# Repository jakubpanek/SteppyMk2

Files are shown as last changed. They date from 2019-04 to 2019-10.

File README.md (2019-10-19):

# Steppy Mk2

The goal of this project is to create a versatile robotic platform for robotic competitions.

It started with a very primitive PCB design that featured just a few, mostly through-hole components and evolved into a much more complicated design with over a hundred SMD components.

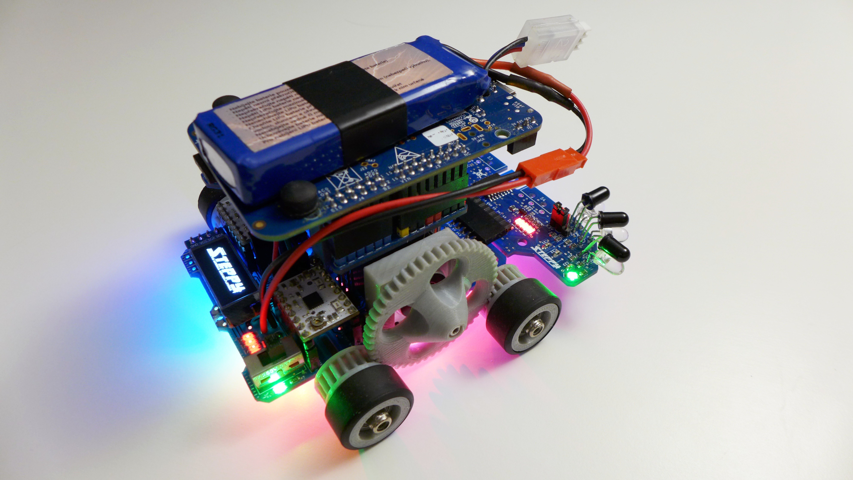
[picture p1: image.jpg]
Drag Racing


## Main features:
- NXP's FRDM dev boards, Arduino compatibility
- Two NEMA8 stepper motors
- Fits onto 100x100mm PCB for cheap manufacturing
- RGB LEDs
- OLED display
- Joystick
- Buzzer
- I²C battery voltage sensor
- Interchangeable sensor board

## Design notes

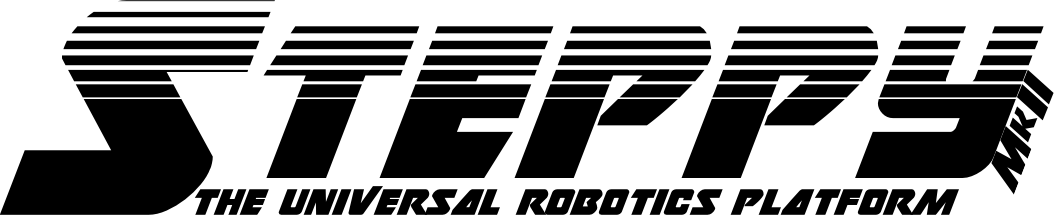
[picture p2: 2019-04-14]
Graphics/SteppyMk2.png

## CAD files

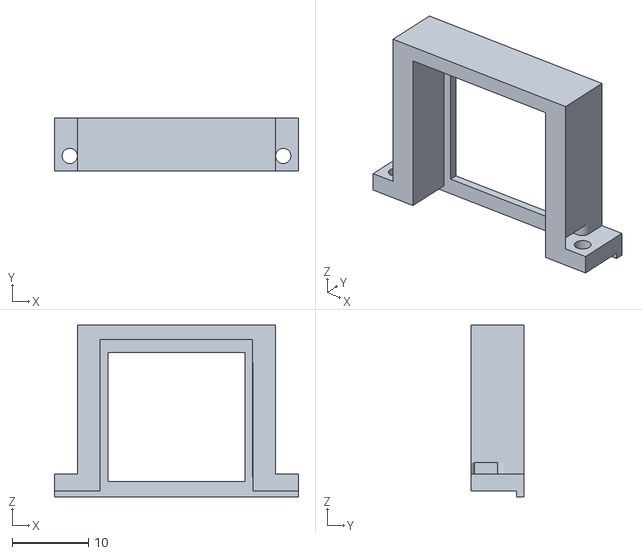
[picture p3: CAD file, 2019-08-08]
3D models/V2.0/MotorHolderSide.stl
32.0 x 7.00 x 22.5

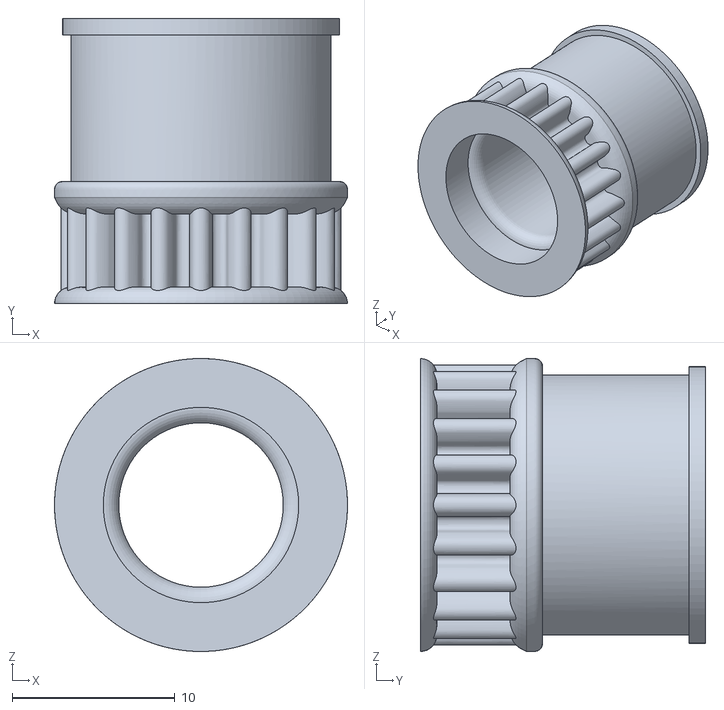
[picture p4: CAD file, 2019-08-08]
3D models/V2.0/Wheel.stl
18.0 x 17.5 x 18.0

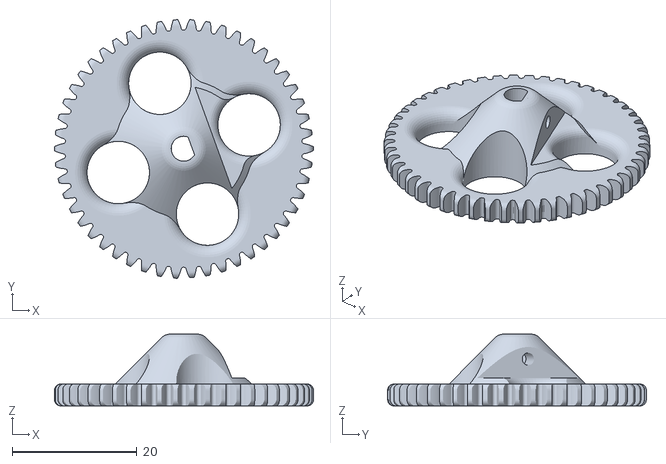
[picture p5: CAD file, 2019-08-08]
3D models/V2.0/Gear.stl
41.5 x 41.5 x 11.5

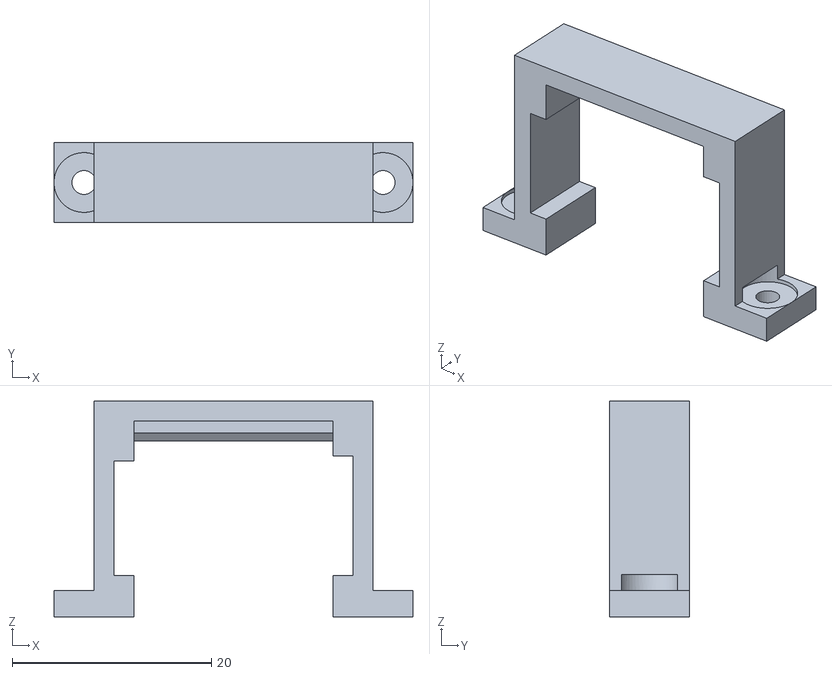
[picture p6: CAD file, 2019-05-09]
3D models/V2.0/MotorHolderMiddle.stl
36.0 x 8.00 x 21.6

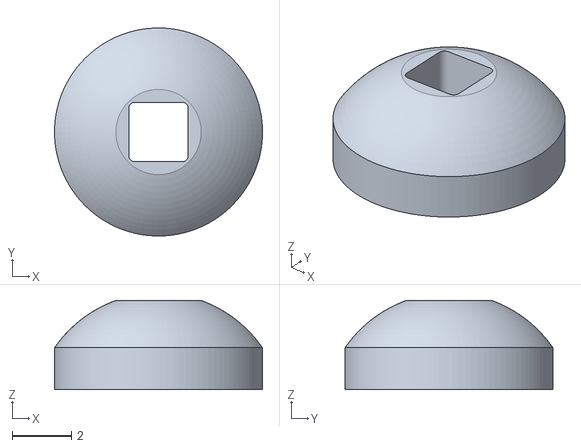
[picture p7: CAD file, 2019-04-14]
3D models/V2.0/JoystickCap.stl
7.00 x 7.00 x 3.00

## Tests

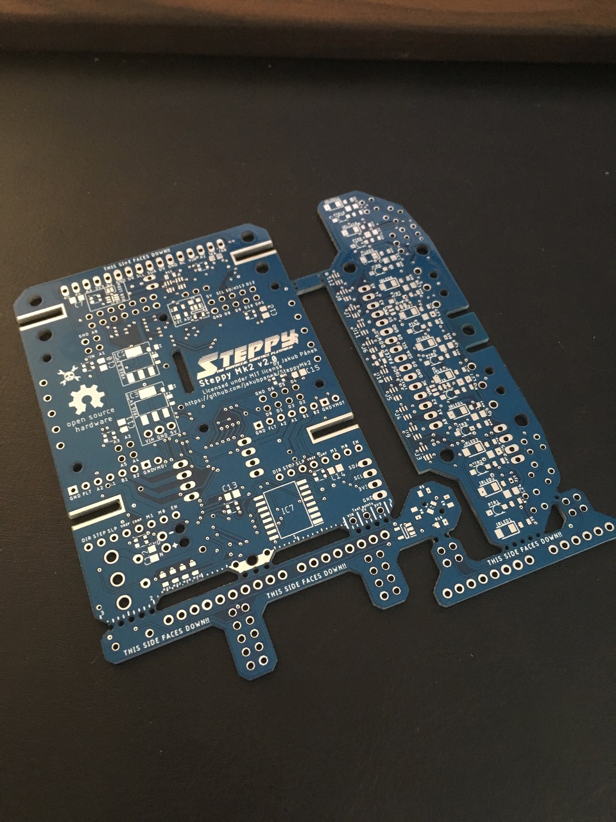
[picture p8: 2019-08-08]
Gerbers/V2.0/Result via JLCPCB/SteppyMk2V2 - 2.jpeg

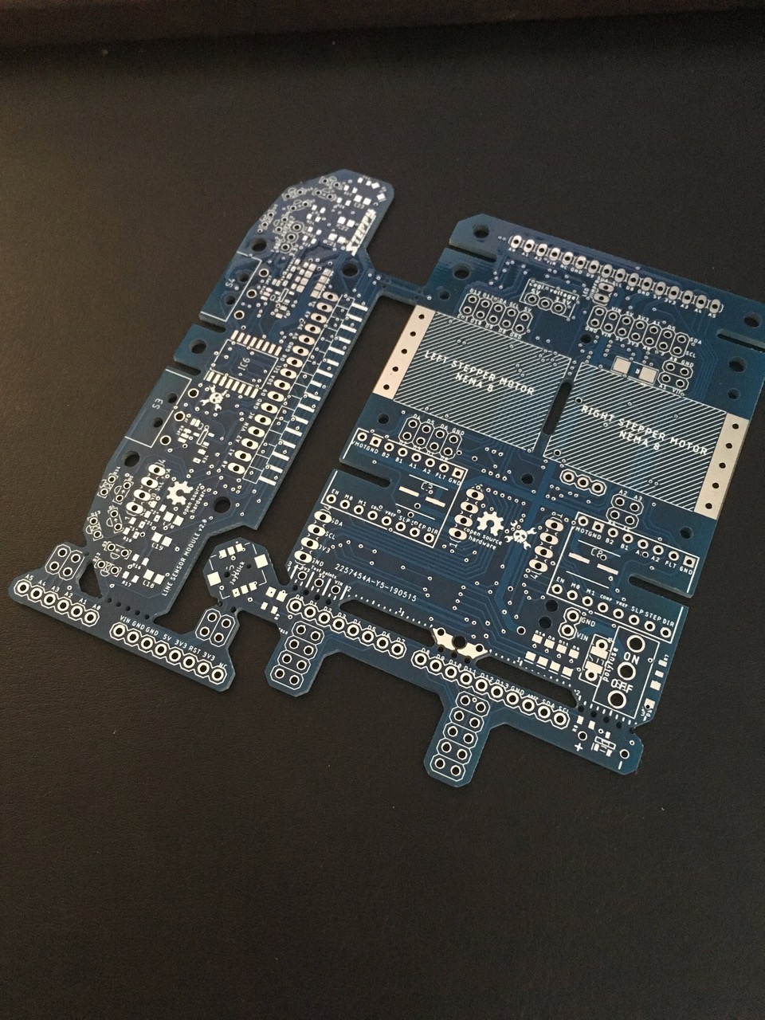
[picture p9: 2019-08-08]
Gerbers/V2.0/Result via JLCPCB/SteppyMk2V2 - 1.jpeg

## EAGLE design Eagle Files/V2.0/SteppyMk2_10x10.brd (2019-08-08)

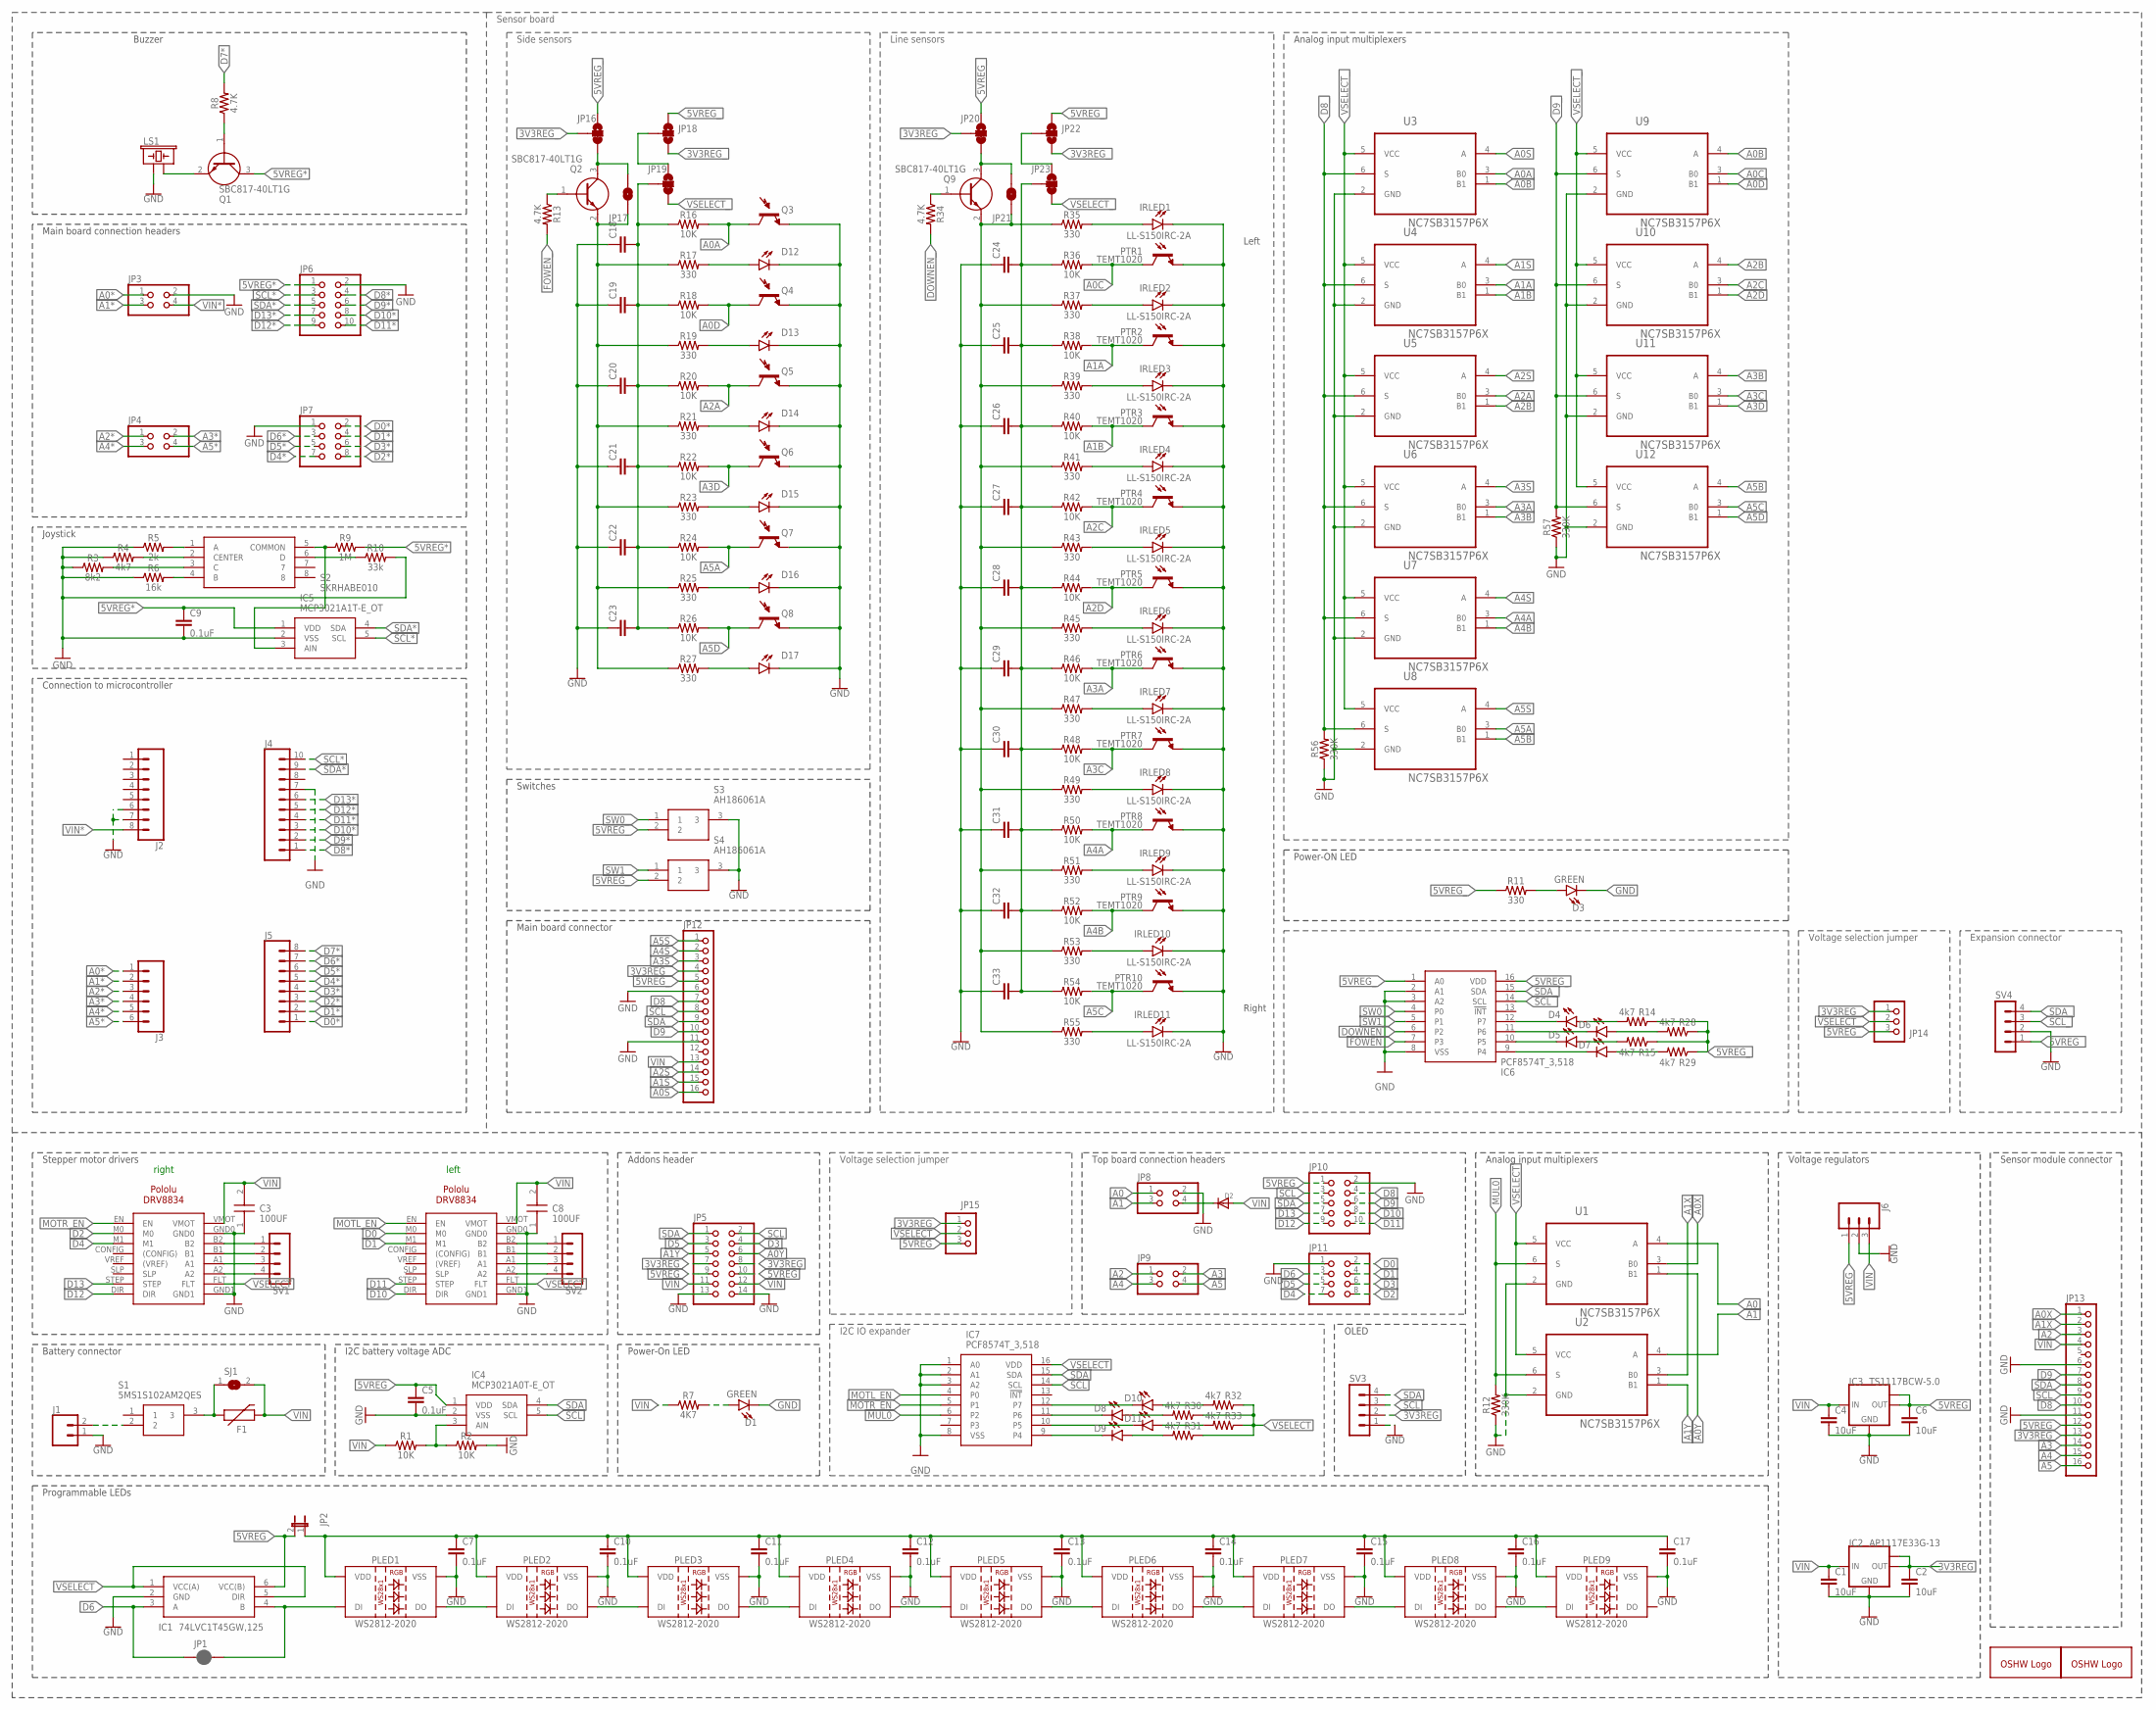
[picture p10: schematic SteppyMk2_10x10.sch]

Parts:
C1, C2, C4, C6: 10uF; 0805
C3, C8: 100UF; CAPM7058X610N
C5: 0.1uF; 0603
C7, C9, C10, C11, C12, C13, C14, C15, C16, C17: 0.1uF; C0805
C18, C19, C20, C21, C22, C23, C24, C25, C26, C27, C28, C29, C30, C31, C32, C33: C-EUC0805; C0805
D1, D3, D4, D5, D6, D7, D8, D9, D10, D11: GREEN; LED-1206
D2: DIODESMA; SMADIODE
D12, D13, D14, D15, D16, D17: LED-IRSIDE_EMITTER; LTE-302
DRV1, DRV2: POLOLU-DRV8825
F1: PPTC_PTH; PTH
GOLD_ORB_SM1: OSHWLOGOLOGO8MM; OSHW_8MM
GOLD_ORB_SM2: OSHWLOGOLOGO5MM; OSHW_5MM
IC1: 74LVC1T45GW,125; SOT65P210X110-6N
IC2: AP1117E33G-13; SOT223
IC3: TS1117BCW-5.0; SOT223
IC4: MCP3021A0T-E_OT; SOT95P280X145-5N
IC5: MCP3021A1T-E_OT; SOT95P280X145-5N
IC6, IC7: PCF8574T_3,518; SOIC127P1032X265-16N
IRLED1, IRLED2, IRLED3, IRLED4, IRLED5, IRLED6, IRLED7, IRLED8, IRLED9, IRLED10, IRLED11: LL-S150IRC-2A; LEDC3215X130N
J1: CONN_02; 1X02
J2, J5: CONN_08"; 1X08
J3: CONN_06SILK_FEMALE_PTH; 1X06
J4: CONN_10"; 1X10
J6: 455-1750-1-ND; 1X03
JP1: JUMPER-SMT_2_NC_PASTE_SILK; SMT-JUMPER_2_NC_PASTE_SILK
JP2: JP1E; JP1
JP3, JP4, JP8, JP9: PINHD-2X2; 2X02
JP5: PINHD-2X7; 2X07
JP6, JP10: PINHD-2X5; 2X05
JP7, JP11: PINHD-2X4; 2X04
JP12: PINHD-1X16/90; 1X16/90
JP13: PINHD-1X16; 1X16
JP14, JP15: PINHD-1X3; 1X03
JP16, JP19, JP20, JP23: JUMPER-SMT_3_1-NC_TRACE_NO-SILK; SMT-JUMPER_3_1-NC_TRACE_NO-SILK
JP17, JP21: JUMPER-SMT_2_NO_NO-SILK; SMT-JUMPER_2_NO_NO-SILK
JP18, JP22: JUMPER-SMT_3_NO_NO_SILK; SMT-JUMPER_3_0-NO_TRACE_NO-SILK
LS1: BUZZER-PTH_NO_SILK; BUZZER-12MM-NS
PLED1, PLED2, PLED3, PLED4, PLED5, PLED6, PLED7, PLED8, PLED9: WS2812-2020
PTR1, PTR2, PTR3, PTR4, PTR5, PTR6, PTR7, PTR8, PTR9, PTR10: TEMT1020
Q1, Q2, Q9: SBC817-40LT1G; SOT96P237X111-3N
Q3, Q4, Q5, Q6, Q7, Q8: LTR-301
R1, R2, R16, R18, R20, R22, R24, R26, R36, R38, R40, R42, R44, R46, R48, R50, R52, R54: 10K; 0805
R3: 8k2; 0805
R4, R14, R15, R28, R29, R30, R31, R32, R33: 4k7; 0805
R5: 2k; 0805
R6: 16k; 0805
R7: 4K7; 0805
R8, R13, R34: 4.7K; 0805
R9: 1M; 0805
R10: 33k; 0805
R11, R17, R19, R21, R23, R25, R27, R35, R37, R39, R41, R43, R45, R47, R49, R51, R53, R55: 330; 0805
R12, R56, R57: 330K; 0805
S1: 5MS1S102AM2QES
S2: SKRHABE010
S3, S4: AH186061A
SJ1: SJW
SV1, SV2, SV3, SV4: MA04-1
U1, U2, U3, U4, U5, U6, U7, U8, U9, U10, U11, U12: NC7SB3157P6X; SOT65P210X110-6N

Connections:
3V3REG: C2.1, IC2.2 (OUT), IC2.TAB (OUT1), JP5.7, JP5.8, JP13.13, JP15.1, SV3.2
3V3REG_: JP12.4, JP14.1, JP16.2, JP18.3, JP20.2, JP22.3
5VREG: C5.1, C6.1, IC1.6 (VCC(B)), IC3.2 (OUT), IC3.TAB (OUT1), IC4.1 (VDD), J6.1, JP2.2, JP5.9, JP5.10, JP10.1, JP13.12, JP15.3
5VREG*: C9.1, IC5.1 (VDD), JP6.1, Q1.3 (C), R9.2
5VREG_: IC6.1 (A0), IC6.16 (VDD), JP12.5, JP14.3, JP16.1, JP18.1, JP20.1, JP22.1, R11.1, R14.1, R15.1, R28.1, R29.1, S3.2, S4.2, SV4.1
A0: JP8.1, U1.4 (A)
A0*: J3.1, JP3.1
A0A: Q3.C (C1), R16.2, U3.3 (B0)
A0B: U3.1 (B1), U9.4 (A)
A0C: PTR1.1 (C), R36.2, U9.3 (B0)
A0D: Q4.C (C1), R18.2, U9.1 (B1)
A0S: JP12.16, U3.4 (A)
A0X: JP13.1, U1.3 (B0)
A0Y: JP5.6, U1.1 (B1)
A1: JP8.3, U2.4 (A)
A1*: J3.2, JP3.3
A1A: PTR2.1 (C), R38.2, U4.3 (B0)
A1B: PTR3.1 (C), R40.2, U4.1 (B1)
A1S: JP12.15, U4.4 (A)
A1X: JP13.2, U2.3 (B0)
A1Y: JP5.5, U2.1 (B1)
A2: JP9.1, JP13.3
A2*: J3.3, JP4.1
A2A: Q5.C (C1), R20.2, U5.3 (B0)
A2B: U5.1 (B1), U10.4 (A)
A2C: PTR4.1 (C), R42.2, U10.3 (B0)
A2D: PTR5.1 (C), R44.2, U10.1 (B1)
A2S: JP12.14, U5.4 (A)
A3: JP9.2, JP13.14
A3*: J3.4, JP4.2
A3A: PTR6.1 (C), R46.2, U6.3 (B0)
A3B: U6.1 (B1), U11.4 (A)
A3C: PTR7.1 (C), R48.2, U11.3 (B0)
A3D: Q6.C (C1), R22.2, U11.1 (B1)
A3S: JP12.3, U6.4 (A)
A4: JP9.3, JP13.15
A4*: J3.5, JP4.3
A4A: PTR8.1 (C), R50.2, U7.3 (B0)
A4B: PTR9.1 (C), R52.2, U7.1 (B1)
A4S: JP12.2, U7.4 (A)
A5: JP9.4, JP13.16
A5*: J3.6, JP4.4
A5A: Q7.C (C1), R24.2, U8.3 (B0)
A5B: U8.1 (B1), U12.4 (A)
A5C: PTR10.1 (C), R54.2, U12.3 (B0)
A5D: Q8.C (C1), R26.2, U12.1 (B1)
A5S: JP12.1, U8.4 (A)
D0: DRV2.M0, JP11.2
D0*: J5.1, JP7.2
D1: DRV2.M1, JP11.4
D1*: J5.2, JP7.4
D2: DRV1.M0, JP11.8
D2*: J5.3, JP7.8
D3: JP5.4, JP11.6
D3*: J5.4, JP7.6
D4: DRV1.M1, JP11.7
D4*: J5.5, JP7.7
D5: JP5.3, JP11.5
D5*: J5.6, JP7.5
D6: IC1.3 (A), JP1.1, JP11.3
D6*: J5.7, JP7.3
D7*: J5.8, R8.2
D8: JP10.4, JP13.10
D8*: J4.1, JP6.4
D8_: JP12.7, R56.2, U3.6 (S), U4.6 (S), U5.6 (S), U6.6 (S), U7.6 (S), U8.6 (S)
D9: JP10.6, JP13.7
D9*: J4.2, JP6.6
D9_: JP12.10, R57.2, U9.6 (S), U10.6 (S), U11.6 (S), U12.6 (S)
D10: DRV2.DIR, JP10.8
D10*: J4.3, JP6.8
D11: DRV2.STEP, JP10.10
D11*: J4.4, JP6.10
D12: DRV1.DIR, JP10.9
D12*: J4.5, JP6.9
D13: DRV1.STEP, JP10.7
D13*: J4.6, JP6.7
DOWNEN_: IC6.6 (P2), R34.2
FOWEN_: IC6.7 (P3), R13.2
GND: C1.2, C2.2, C3.1, C4.2, C5.2, C6.2, C7.2, C8.1, C9.2, C10.2, C11.2, C12.2, C13.2, C14.2, C15.2, C16.2, C17.2, C18.1, C19.1, C20.1, C21.1, C22.1, C23.1, C24.1, C25.1, C26.1, C27.1, C28.1, C29.1, C30.1, C31.1, C32.1, C33.1, D1.C, D3.C, D12.C, D13.C, D14.C, D15.C, D16.C, D17.C, DRV1.GND0, DRV1.GND1, DRV2.GND0, DRV2.GND1, IC1.2 (GND), IC2.1 (GND), IC3.1 (GND), IC4.2 (VSS), IC5.2 (VSS), IC6.2 (A1), IC6.3 (A2), IC6.8 (VSS), IC7.1 (A0), IC7.2 (A1), IC7.3 (A2), IC7.8 (VSS), IRLED1.2 (C), IRLED2.2 (C), IRLED3.2 (C), IRLED4.2 (C), IRLED5.2 (C), IRLED6.2 (C), IRLED7.2 (C), IRLED8.2 (C), IRLED9.2 (C), IRLED10.2 (C), IRLED11.2 (C), J1.1, J2.6, J2.7, J4.7, J6.2, JP3.2, JP5.13, JP5.14, JP6.2, JP7.1, JP8.2, JP10.2, JP11.1, JP12.6, JP12.11, JP13.6, JP13.11, LS1.+ (1), PLED1.2 (VSS), PLED2.2 (VSS), PLED3.2 (VSS), PLED4.2 (VSS), PLED5.2 (VSS), PLED6.2 (VSS), PLED7.2 (VSS), PLED8.2 (VSS), PLED9.2 (VSS), PTR1.2 (E), PTR2.2 (E), PTR3.2 (E), PTR4.2 (E), PTR5.2 (E), PTR6.2 (E), PTR7.2 (E), PTR8.2 (E), PTR9.2 (E), PTR10.2 (E), Q3.E (E1), Q4.E (E1), Q5.E (E1), Q6.E (E1), Q7.E (E1), Q8.E (E1), R2.2, R3.1, R4.1, R5.1, R6.1, R10.2, R12.1, R56.1, R57.1, S3.3, S4.3, SV3.1, SV4.2, U1.2 (GND), U2.2 (GND), U3.2 (GND), U4.2 (GND), U5.2 (GND), U6.2 (GND), U7.2 (GND), U8.2 (GND), U9.2 (GND), U10.2 (GND), U11.2 (GND), U12.2 (GND)
GND1: D6.C, IC6.11 (P6)
GND2: D5.C, IC6.10 (P5)
GND3: D7.C, IC6.9 (P4)
MOTL_EN: DRV2.EN, IC7.4 (P0)
MOTR_EN: DRV1.EN, IC7.5 (P1)
MUL0: IC7.6 (P2), R12.2, U1.6 (S), U2.6 (S)
unnamed: IRLED9.1 (A), R51.2
unnamed: IRLED2.1 (A), R37.2
unnamed: D4.A, R14.2
unnamed: D2.C, JP8.4
unnamed: Q2.1 (B), R13.1
unnamed: IRLED1.1 (A), R35.2
unnamed: IC1.4 (B), JP1.2, PLED1.3 (DI)
unnamed: D8.A, R30.2
unnamed: D11.C, IC7.10 (P5)
unnamed: D9.A, R31.2
unnamed: PLED6.1 (DO), PLED7.3 (DI)
unnamed: IRLED3.1 (A), R39.2
unnamed: PLED7.1 (DO), PLED8.3 (DI)
unnamed: PLED8.1 (DO), PLED9.3 (DI)
unnamed: D1.A, R7.2
unnamed: DRV2.B2, SV2.1
unnamed: DRV2.B1, SV2.2
unnamed: DRV2.A1, SV2.3
unnamed: DRV2.A2, SV2.4
unnamed: D6.A, R28.2
unnamed: R6.2, S2.4 (B)
unnamed: D3.A, R11.2
unnamed: IRLED4.1 (A), R41.2
unnamed: D5.A, R15.2
unnamed: R3.2, S2.3 (C)
unnamed: DRV1.B2, SV1.1
unnamed: DRV1.B1, SV1.2
unnamed: DRV1.A1, SV1.3
unnamed: DRV1.A2, SV1.4
unnamed: J1.2, S1.2
unnamed: R4.2, S2.2 (CENTER)
unnamed: LS1.- (2), Q1.2 (E)
unnamed: Q1.1 (B), R8.1
unnamed: IC4.3 (AIN), R1.2, R2.1
unnamed: R5.2, S2.1 (A)
unnamed: D10.C, IC7.12 (P7)
unnamed: IC5.3 (AIN), R9.1, S2.5 (COMMON)
unnamed: R10.1, S2.6 (D)
unnamed: D8.C, IC7.11 (P6)
unnamed: D7.A, R29.2
unnamed: D9.C, IC7.9 (P4)
unnamed: D11.A, R33.2
unnamed: D10.A, R32.2
unnamed: C7.1, C10.1, C11.1, C12.1, C13.1, C14.1, C15.1, C16.1, C17.1, JP2.1, PLED1.4 (VDD), PLED2.4 (VDD), PLED3.4 (VDD), PLED4.4 (VDD), PLED5.4 (VDD), PLED6.4 (VDD), PLED7.4 (VDD), PLED8.4 (VDD), PLED9.4 (VDD)
unnamed: IRLED5.1 (A), R43.2
unnamed: PLED2.1 (DO), PLED3.3 (DI)
unnamed: PLED3.1 (DO), PLED4.3 (DI)
unnamed: IRLED6.1 (A), R45.2
unnamed: PLED4.1 (DO), PLED5.3 (DI)
unnamed: IRLED7.1 (A), R47.2
unnamed: PLED5.1 (DO), PLED6.3 (DI)
unnamed: JP16.3, JP17.2, Q2.3 (C)
unnamed: IRLED8.1 (A), R49.2
unnamed: JP18.2, JP19.1
unnamed: PLED1.1 (DO), PLED2.3 (DI)
unnamed: JP22.2, JP23.1
unnamed: JP20.3, JP21.2, Q9.3 (C)
unnamed: D4.C, IC6.12 (P7)
unnamed: IRLED10.1 (A), R53.2
unnamed: IRLED11.1 (A), R55.2
unnamed: D12.A, R17.2
unnamed: D13.A, R19.2
unnamed: Q9.1 (B), R34.1
unnamed: D14.A, R21.2
unnamed: F1.P$1 (1), S1.3, SJ1.1
unnamed: D15.A, R23.2
unnamed: JP21.1, Q9.2 (E), R35.1, R37.1, R39.1, R41.1, R43.1, R45.1, R47.1, R49.1, R51.1, R53.1, R55.1
unnamed: D16.A, R25.2
unnamed: D17.A, R27.2
unnamed: JP17.1, Q2.2 (E), R17.1, R19.1, R21.1, R23.1, R25.1, R27.1
NE9878: C24.2, C25.2, C26.2, C27.2, C28.2, C29.2, C30.2, C31.2, C32.2, C33.2, JP23.2, R36.1, R38.1, R40.1, R42.1, R44.1, R46.1, R48.1, R50.1, R52.1, R54.1
NET56SDFSF: C18.2, C19.2, C20.2, C21.2, C22.2, C23.2, JP19.2, R16.1, R18.1, R20.1, R22.1, R24.1, R26.1
SCL: IC4.5 (SCL), IC7.14 (SCL), JP5.2, JP10.3, JP13.9, SV3.3
SCL*: IC5.5 (SCL), J4.10, JP6.3
SCL_: IC6.14 (SCL), JP12.8, SV4.3
SDA: IC4.4 (SDA), IC7.15 (SDA), JP5.1, JP10.5, JP13.8, SV3.4
SDA*: IC5.4 (SDA), J4.9, JP6.5
SDA_: IC6.15 (SDA), JP12.9, SV4.4
SW0_: IC6.4 (P0), S3.1
SW1_: IC6.5 (P1), S4.1
VIN: C1.1, C3.2, C4.1, C8.2, D2.A, DRV1.VMOT, DRV2.VMOT, F1.P$2 (2), IC2.3 (IN), IC3.3 (IN), J6.3, JP5.11, JP5.12, JP13.4, R1.1, R7.1, SJ1.2
VIN*: J2.8, JP3.4
VIN_: JP12.13
VSELECT: DRV1.FLT, DRV2.FLT, IC1.1 (VCC(A)), IC1.5 (DIR), IC7.16 (VDD), JP15.2, R30.1, R31.1, R32.1, R33.1, U1.5 (VCC), U2.5 (VCC)
VSELECT_: JP14.2, JP19.3, JP23.3, U3.5 (VCC), U4.5 (VCC), U5.5 (VCC), U6.5 (VCC), U7.5 (VCC), U8.5 (VCC), U9.5 (VCC), U10.5 (VCC), U11.5 (VCC), U12.5 (VCC)

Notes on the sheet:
Battery connector
I2C battery voltage ADC
Programmable LEDs
Stepper motor drivers
Voltage regulators
Buzzer
Joystick
Right
Left
Addons header
OLED
Connection to microcontroller
Main board connection headers
Top board connection headers
Sensor module connector
Main board connector
Power-ON LED
Power-On LED
Switches
Analog input multiplexers
left
right
Voltage selection jumper
I2C IO expander
Expansion connector
Sensor board
Line sensors
Side sensors

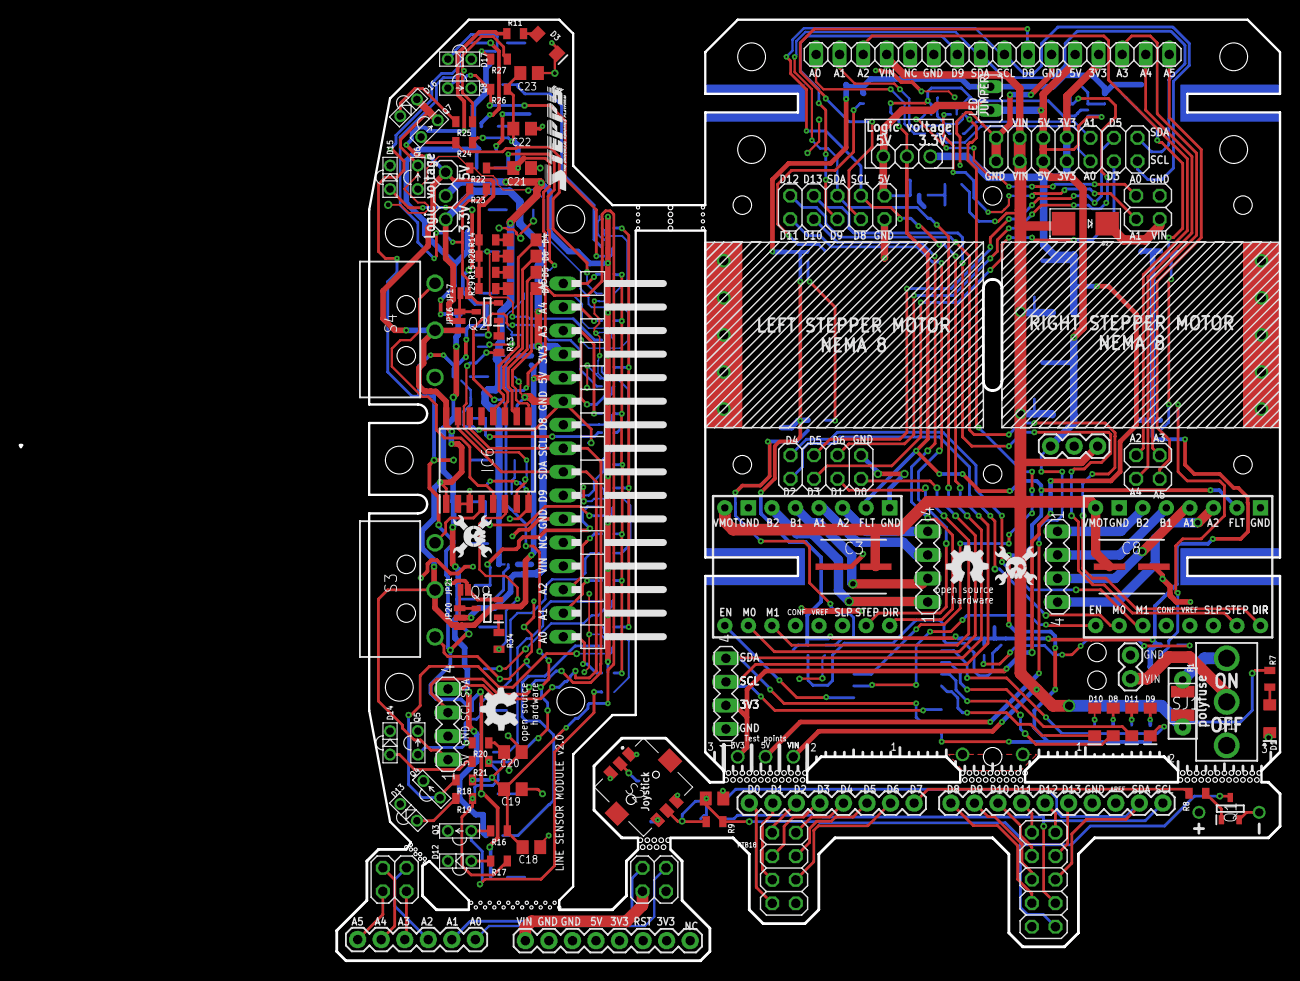
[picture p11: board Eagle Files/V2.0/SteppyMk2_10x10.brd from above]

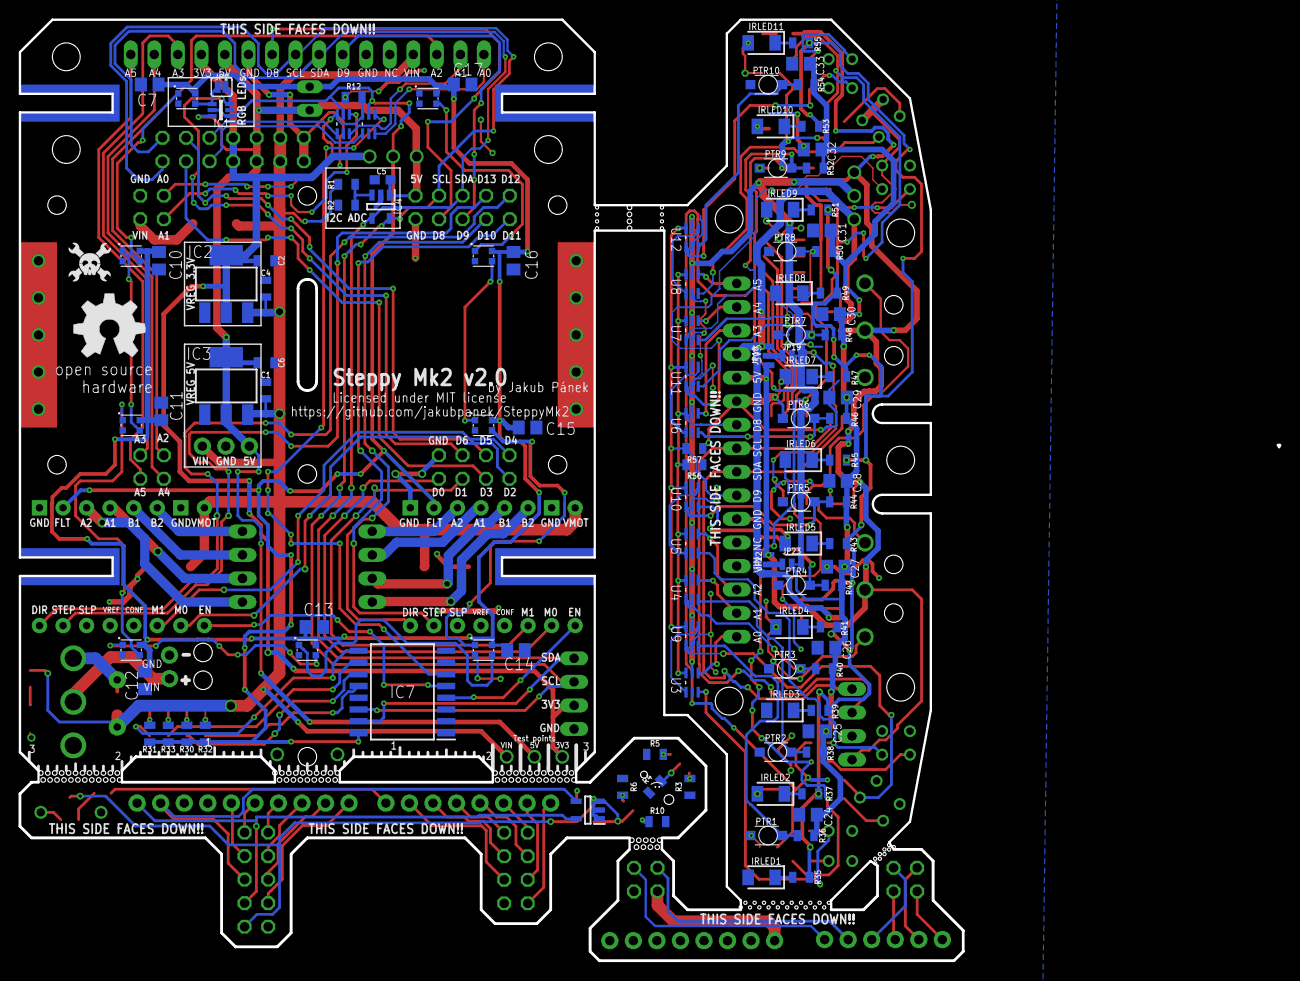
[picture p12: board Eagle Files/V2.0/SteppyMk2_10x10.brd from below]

Board: 2 copper layers, 101.8 x 101.5 mm, 210 parts (113 on the bottom side), 169 nets.

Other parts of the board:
GOLD_ORB_SM3: OSHWLOGOLOGO5MM; OSHW_5MM

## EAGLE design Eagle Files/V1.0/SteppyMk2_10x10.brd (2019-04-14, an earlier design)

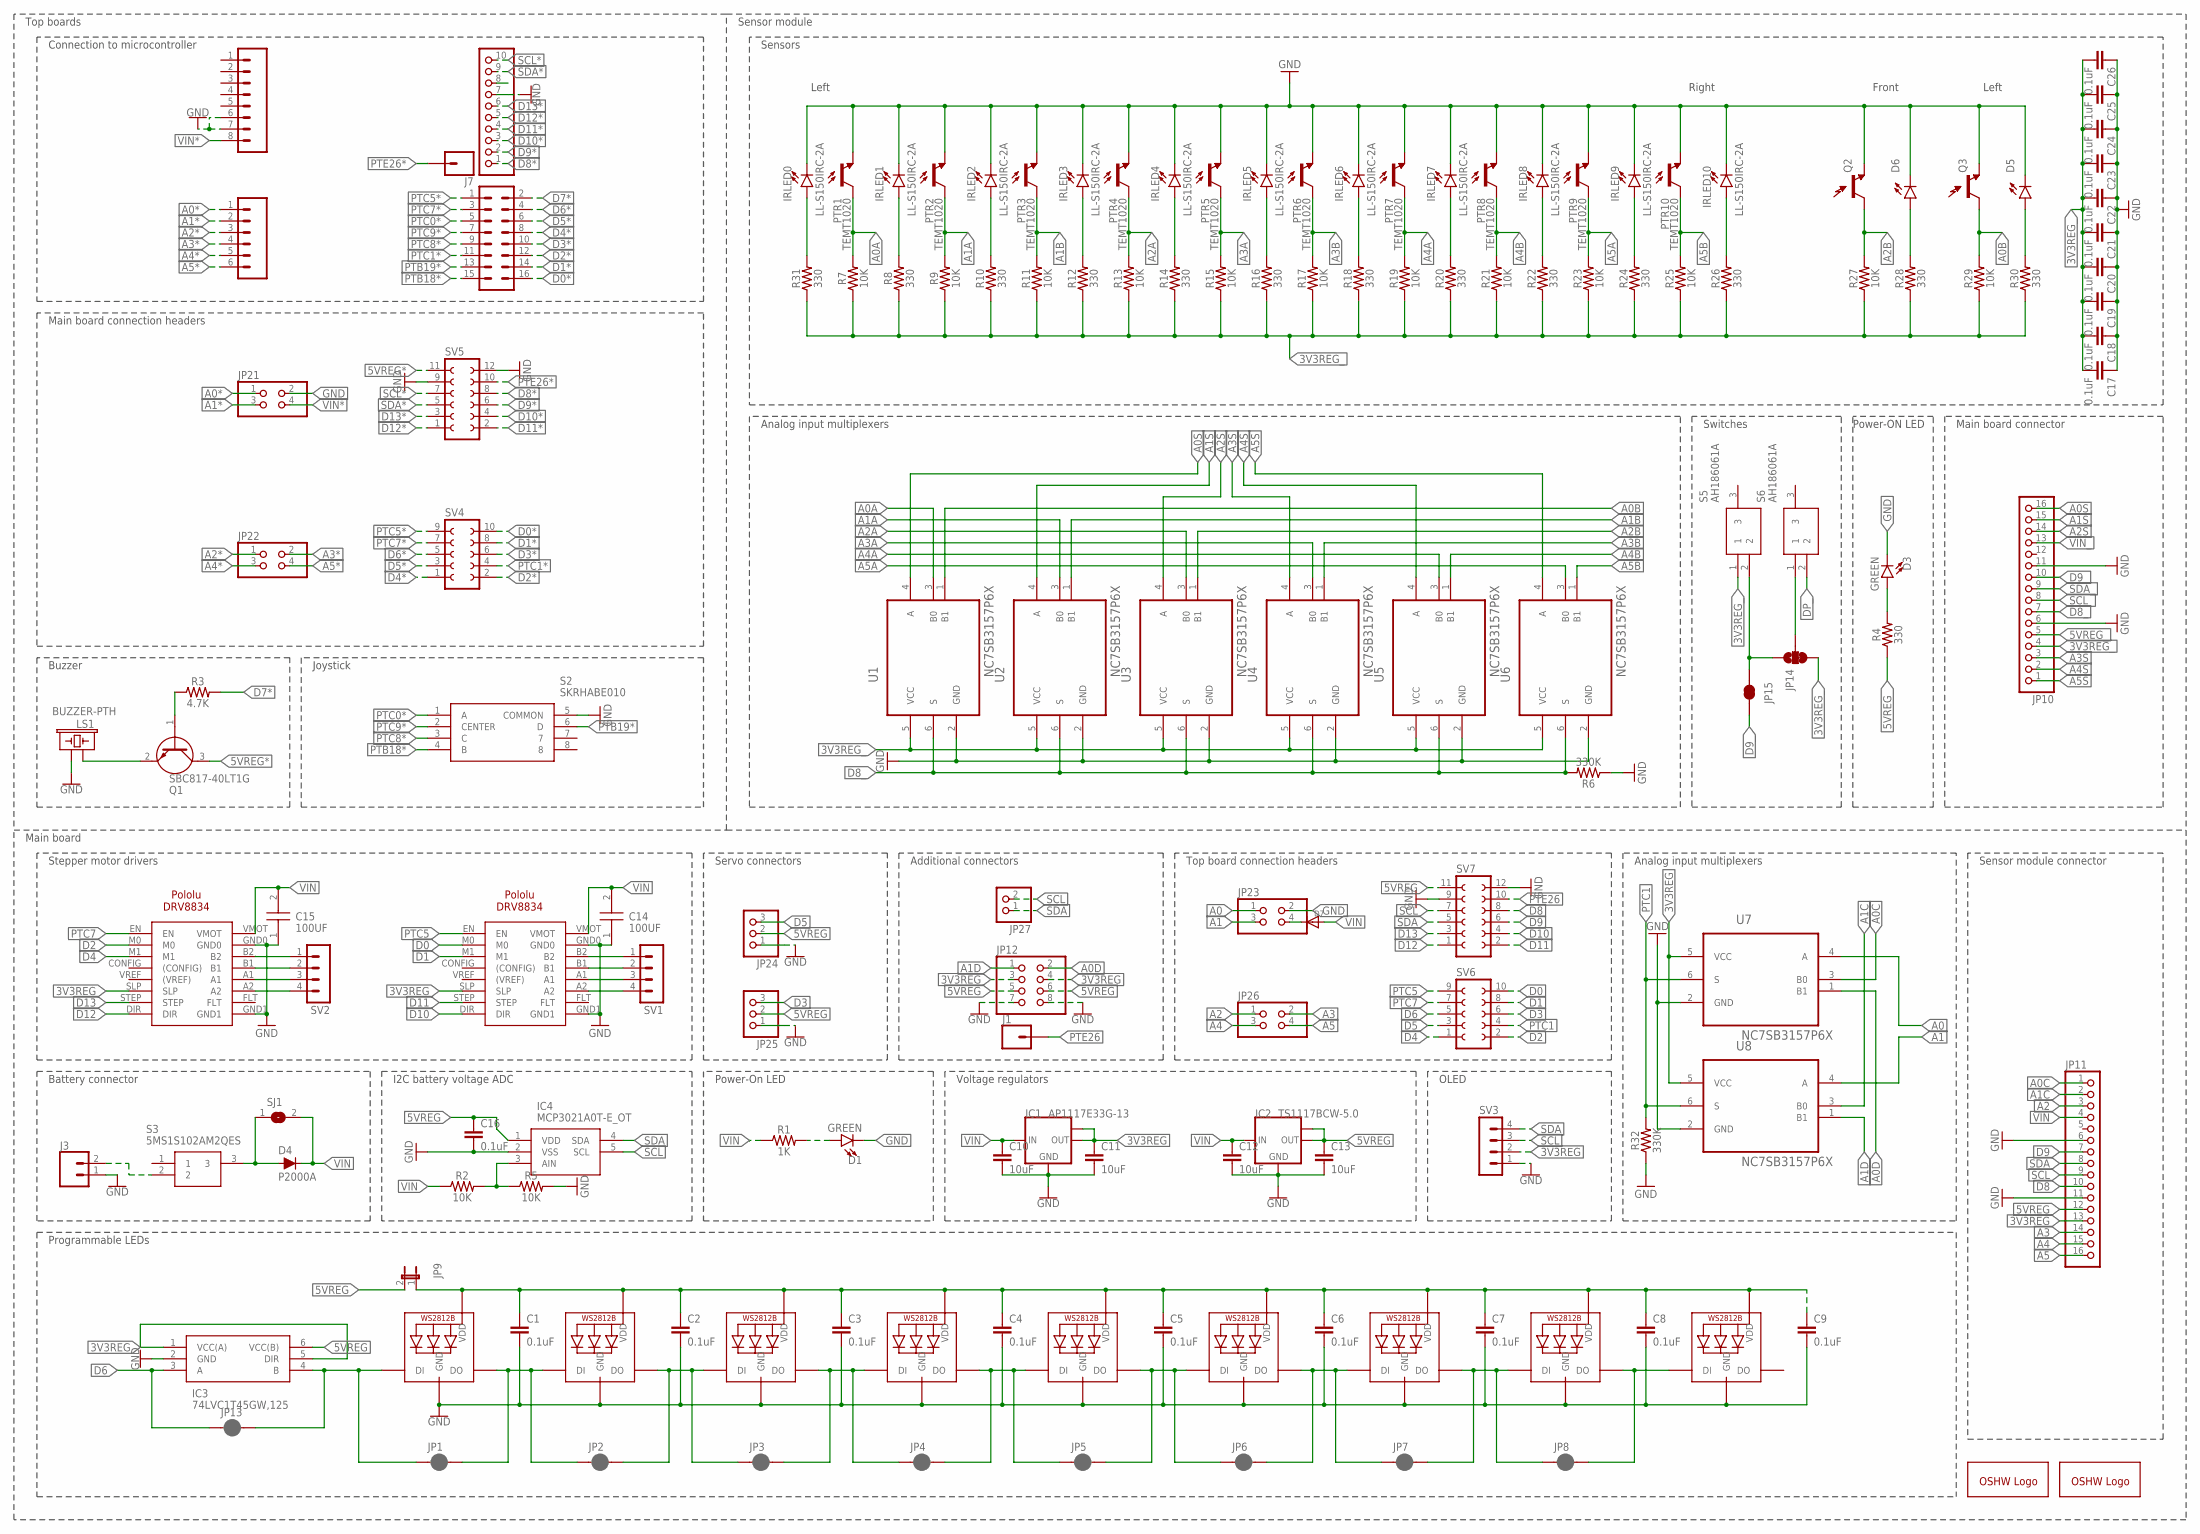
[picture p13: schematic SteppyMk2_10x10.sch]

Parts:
C1, C2, C3, C4, C5, C6, C7, C8, C9, C16, C17, C18, C19, C20, C21, C22, C23, C24, C25, C26: 0.1uF; 0603
C10, C11, C12, C13: 10uF; 0805
C14, C15: 100UF; CAPM7058X610N
CONLEFT: POLOLU-DRV8825
D1, D3: GREEN; LED-1206
D4: P2000A; DIODE-1N4001
D5, D6: LED-IRSIDE_EMITTER; LTE-302
D7: DIODESMA; SMADIODE
GOLD_ORB_SM1: OSHWLOGOLOGO8MM; OSHW_8MM
GOLD_ORB_SM2: OSHWLOGOLOGO5MM; OSHW_5MM
IC1: AP1117E33G-13; SOT223
IC2: TS1117BCW-5.0; SOT223
IC3: 74LVC1T45GW,125; SOT65P210X110-6N
IC4: MCP3021A0T-E_OT; SOT95P280X145-5N
IRLED0, IRLED1, IRLED2, IRLED3, IRLED4, IRLED5, IRLED6, IRLED7, IRLED8, IRLED9, IRLED10: LL-S150IRC-2A; LEDC3215X130N
J1, J7: CONN_01; 1X01
J3: CONN_02; 1X02
J5: CONN_08"; 1X08
J6: CONN_06SILK_FEMALE_PTH; 1X06
J8: CONN_08X2_HEADER; 2X8
JP1, JP2, JP3, JP4, JP5, JP6, JP7, JP8, JP13: JUMPER-SMT_2_NC_PASTE_SILK; SMT-JUMPER_2_NC_PASTE_SILK
JP9: JP1E; JP1
JP10: PINHD-1X16/90; 1X16/90
JP11: PINHD-1X16; 1X16
JP12: PINHD-2X4; 2X04
JP14: JUMPER-SMT_3_1-NC_TRACE_SILK; SMT-JUMPER_3_1-NC_TRACE_SILK
JP15: JUMPER-SMT_2_NC_TRACE_SILK; SMT-JUMPER_2_NC_TRACE_SILK
JP21, JP22, JP23, JP26: PINHD-2X2; 2X02
JP24, JP25: PINHD-1X3; 1X03
JP27: PINHD-1X2; 1X02
LED1, LED2, LED3, LED4, LED5, LED6, LED7, LED8, LED9: WS2812B3535; LED3535
LS1: BUZZER-PTH; BUZZER-12MM
PTR1, PTR2, PTR3, PTR4, PTR5, PTR6, PTR7, PTR8, PTR9, PTR10: TEMT1020
Q1: SBC817-40LT1G; SOT96P237X111-3N
Q2, Q3: LTR-301
R1: 1K; 0805
R2, R5, R7, R9, R11, R13, R15, R17, R19, R21, R23, R25, R27, R29: 10K; 0805
R3: 4.7K; 0805
R4, R8, R10, R12, R14, R16, R18, R20, R22, R24, R26, R28, R30, R31: 330; 0805
R6, R32: 330K; 0805
S2: SKRHABE010
S3: 5MS1S102AM2QES
S5, S6: AH186061A
SJ1: SJW
SV1, SV2, SV3: MA04-1
SV4, SV6: FE05-2
SV5, SV7: FE06-2
U1, U2, U3, U4, U5, U6, U7, U8: NC7SB3157P6X; SOT65P210X110-6N
U$1: PINHD-1X10; 1X10-BIG
U$2: POLOLU-DRV8825

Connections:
3V3REG: C11.1, CONLEFT.SLP, IC1.2 (OUT), IC1.TAB (OUT1), IC3.1 (VCC(A)), IC3.5 (DIR), JP11.13, JP12.3, JP12.4, SV3.2, U7.5 (VCC), U8.5 (VCC), U$2.SLP
3V3REG_: C17.2, C18.2, C19.2, C20.2, C21.2, C22.2, C23.2, C24.2, C25.2, C26.2, JP10.4, JP14.3, R7.1, R8.1, R9.1, R10.1, R11.1, R12.1, R13.1, R14.1, R15.1, R16.1, R17.1, R18.1, R19.1, R20.1, R21.1, R22.1, R23.1, R24.1, R25.1, R26.1, R27.1, R28.1, R29.1, R30.1, R31.1, S5.1, U1.5 (VCC), U2.5 (VCC), U3.5 (VCC), U4.5 (VCC), U5.5 (VCC), U6.5 (VCC)
5VREG: C13.1, C16.1, IC2.2 (OUT), IC2.TAB (OUT1), IC3.6 (VCC(B)), IC4.1 (VDD), JP9.2, JP11.12, JP12.5, JP12.6, JP24.2, JP25.2, SV7.11
5VREG*: Q1.3 (C), SV5.11
5VREG_: JP10.5, R4.1
A0: JP23.1, U7.4 (A)
A0*: J6.1, JP21.1
A0A: PTR1.1 (C), R7.2, U1.3 (B0)
A0B: Q3.C (C1), R29.2, U1.1 (B1)
A0C: JP11.1, U7.3 (B0)
A0D: JP12.2, U7.1 (B1)
A0S: JP10.16, U1.4 (A)
A1: JP23.3, U8.4 (A)
A1*: J6.2, JP21.3
A1A: PTR2.1 (C), R9.2, U2.3 (B0)
A1B: PTR3.1 (C), R11.2, U2.1 (B1)
A1C: JP11.2, U8.3 (B0)
A1D: JP12.1, U8.1 (B1)
A1S: JP10.15, U2.4 (A)
A2: JP11.3, JP26.1
A2*: J6.3, JP22.1
A2A: PTR4.1 (C), R13.2, U3.3 (B0)
A2B: Q2.C (C1), R27.2, U3.1 (B1)
A2S: JP10.14, U3.4 (A)
A3: JP11.14, JP26.2
A3*: J6.4, JP22.2
A3A: PTR5.1 (C), R15.2, U4.3 (B0)
A3B: PTR6.1 (C), R17.2, U4.1 (B1)
A3S: JP10.3, U4.4 (A)
A4: JP11.15, JP26.3
A4*: J6.5, JP22.3
A4A: PTR7.1 (C), R19.2, U5.3 (B0)
A4B: PTR8.1 (C), R21.2, U5.1 (B1)
A4S: JP10.2, U5.4 (A)
A5: JP11.16, JP26.4
A5*: J6.6, JP22.4
A5A: PTR9.1 (C), R23.2, U6.3 (B0)
A5B: PTR10.1 (C), R25.2, U6.1 (B1)
A5S: JP10.1, U6.4 (A)
D0: SV6.10, U$2.M0
D0*: J8.16, SV4.10
D1: SV6.8, U$2.M1
D1*: J8.14, SV4.8
D2: CONLEFT.M0, SV6.2
D2*: J8.12, SV4.2
D3: JP25.3, SV6.6
D3*: J8.10, SV4.6
D4: CONLEFT.M1, SV6.1
D4*: J8.8, SV4.1
D5: JP24.3, SV6.3
D5*: J8.6, SV4.3
D6: IC3.3 (A), JP13.1, SV6.5
D6*: J8.4, SV4.5
D7*: J8.2, R3.2
D8: JP11.10, SV7.8
D8*: SV5.8, U$1.1
D8_: JP10.7, R6.2, U1.6 (S), U2.6 (S), U3.6 (S), U4.6 (S), U5.6 (S), U6.6 (S)
D9: JP11.7, SV7.6
D9*: SV5.6, U$1.2
D9_: JP10.10, JP15.1
D10: SV7.4, U$2.DIR
D10*: SV5.4, U$1.3
D11: SV7.2, U$2.STEP
D11*: SV5.2, U$1.4
D12: CONLEFT.DIR, SV7.1
D12*: SV5.1, U$1.5
D13: CONLEFT.STEP, SV7.3
D13*: SV5.3, U$1.6
DP_: S6.2
GND: C1.2, C2.2, C3.2, C4.2, C5.2, C6.2, C7.2, C8.2, C9.2, C10.2, C11.2, C12.2, C13.2, C14.1, C15.1, C16.2, C17.1, C18.1, C19.1, C20.1, C21.1, C22.1, C23.1, C24.1, C25.1, C26.1, CONLEFT.GND0, CONLEFT.GND1, D1.C, D3.C, D5.C, D6.C, IC1.1 (GND), IC2.1 (GND), IC3.2 (GND), IC4.2 (VSS), IRLED0.2 (C), IRLED1.2 (C), IRLED2.2 (C), IRLED3.2 (C), IRLED4.2 (C), IRLED5.2 (C), IRLED6.2 (C), IRLED7.2 (C), IRLED8.2 (C), IRLED9.2 (C), IRLED10.2 (C), J3.1, J5.6, J5.7, JP10.6, JP10.11, JP11.6, JP11.11, JP12.7, JP12.8, JP21.2, JP23.2, JP24.1, JP25.1, LED1.4 (GND), LED2.4 (GND), LED3.4 (GND), LED4.4 (GND), LED5.4 (GND), LED6.4 (GND), LED7.4 (GND), LED8.4 (GND), LED9.4 (GND), LS1.- (2), PTR1.2 (E), PTR2.2 (E), PTR3.2 (E), PTR4.2 (E), PTR5.2 (E), PTR6.2 (E), PTR7.2 (E), PTR8.2 (E), PTR9.2 (E), PTR10.2 (E), Q2.E (E1), Q3.E (E1), R5.2, R6.1, R32.1, S2.5 (COMMON), SV3.1, SV5.9, SV5.12, SV7.9, SV7.12, U1.2 (GND), U2.2 (GND), U3.2 (GND), U4.2 (GND), U5.2 (GND), U6.2 (GND), U7.2 (GND), U8.2 (GND), U$1.7, U$2.GND0, U$2.GND1
unnamed: IRLED8.1 (A), R22.2
unnamed: IRLED1.1 (A), R8.2
unnamed: D6.A, R28.2
unnamed: D7.C, JP23.4
unnamed: JP14.2, S6.1
unnamed: IRLED0.1 (A), R31.2
unnamed: IC3.4 (B), JP1.1, JP13.2, LED1.1 (DI)
unnamed: JP2.2, JP3.1, LED2.3 (DO), LED3.1 (DI)
unnamed: JP3.2, JP4.1, LED3.3 (DO), LED4.1 (DI)
unnamed: JP4.2, JP5.1, LED4.3 (DO), LED5.1 (DI)
unnamed: JP5.2, JP6.1, LED5.3 (DO), LED6.1 (DI)
unnamed: JP6.2, JP7.1, LED6.3 (DO), LED7.1 (DI)
unnamed: IRLED2.1 (A), R10.2
unnamed: JP7.2, JP8.1, LED7.3 (DO), LED8.1 (DI)
unnamed: JP8.2, LED8.3 (DO), LED9.1 (DI)
unnamed: D1.A, R1.2
unnamed: SV1.1, U$2.B2
unnamed: SV1.2, U$2.B1
unnamed: SV1.3, U$2.A1
unnamed: SV1.4, U$2.A2
unnamed: D5.A, R30.2
unnamed: D3.A, R4.2
unnamed: IRLED3.1 (A), R12.2
unnamed: CONLEFT.B2, SV2.1
unnamed: CONLEFT.B1, SV2.2
unnamed: CONLEFT.A1, SV2.3
unnamed: CONLEFT.A2, SV2.4
unnamed: J3.2, S3.2
unnamed: LS1.+ (1), Q1.2 (E)
unnamed: Q1.1 (B), R3.1
unnamed: IC4.3 (AIN), R2.2, R5.1
unnamed: C1.1, C2.1, C3.1, C4.1, C5.1, C6.1, C7.1, C8.1, C9.1, JP9.1, LED1.2 (VDD), LED2.2 (VDD), LED3.2 (VDD), LED4.2 (VDD), LED5.2 (VDD), LED6.2 (VDD), LED7.2 (VDD), LED8.2 (VDD), LED9.2 (VDD)
unnamed: IRLED4.1 (A), R14.2
unnamed: IRLED5.1 (A), R16.2
unnamed: IRLED6.1 (A), R18.2
unnamed: IRLED7.1 (A), R20.2
unnamed: IRLED9.1 (A), R24.2
unnamed: JP14.1, JP15.2, S5.2
unnamed: IRLED10.1 (A), R26.2
unnamed: JP1.2, JP2.1, LED1.3 (DO), LED2.1 (DI)
unnamed: D4.A, S3.3, SJ1.1
PTB18*: J8.15, S2.4 (B)
PTB19*: J8.13, S2.6 (D)
PTC0*: J8.5, S2.1 (A)
PTC1: R32.2, SV6.4, U7.6 (S), U8.6 (S)
PTC1*: J8.11, SV4.4
PTC5: SV6.9, U$2.EN
PTC5*: J8.1, SV4.9
PTC7: CONLEFT.EN, SV6.7
PTC7*: J8.3, SV4.7
PTC8*: J8.9, S2.3 (C)
PTC9*: J8.7, S2.2 (CENTER)
PTE26: J1.1, SV7.10
PTE26*: J7.1, SV5.10
SCL: IC4.5 (SCL), JP11.9, JP27.2, SV3.3, SV7.7
SCL*: SV5.7, U$1.10
SCL_: JP10.8
SDA: IC4.4 (SDA), JP11.8, JP27.1, SV3.4, SV7.5
SDA*: SV5.5, U$1.9
SDA_: JP10.9
VIN: C10.1, C12.1, C14.2, C15.2, CONLEFT.VMOT, D4.C, D7.A, IC1.3 (IN), IC2.3 (IN), JP11.4, R1.1, R2.1, SJ1.2, U$2.VMOT
VIN*: J5.8, JP21.4
VIN_: JP10.13

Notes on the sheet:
Battery connector
I2C battery voltage ADC
Programmable LEDs
Stepper motor drivers
Servo connectors
Voltage regulators
Buzzer
Joystick
Front
Left
Right
Additional connectors
OLED
Connection to microcontroller
Main board connection headers
Top board connection headers
Sensor module connector
Main board connector
Power-ON LED
Power-On LED
Switches
Analog input multiplexers
Sensors
Main board
Top boards
Sensor module

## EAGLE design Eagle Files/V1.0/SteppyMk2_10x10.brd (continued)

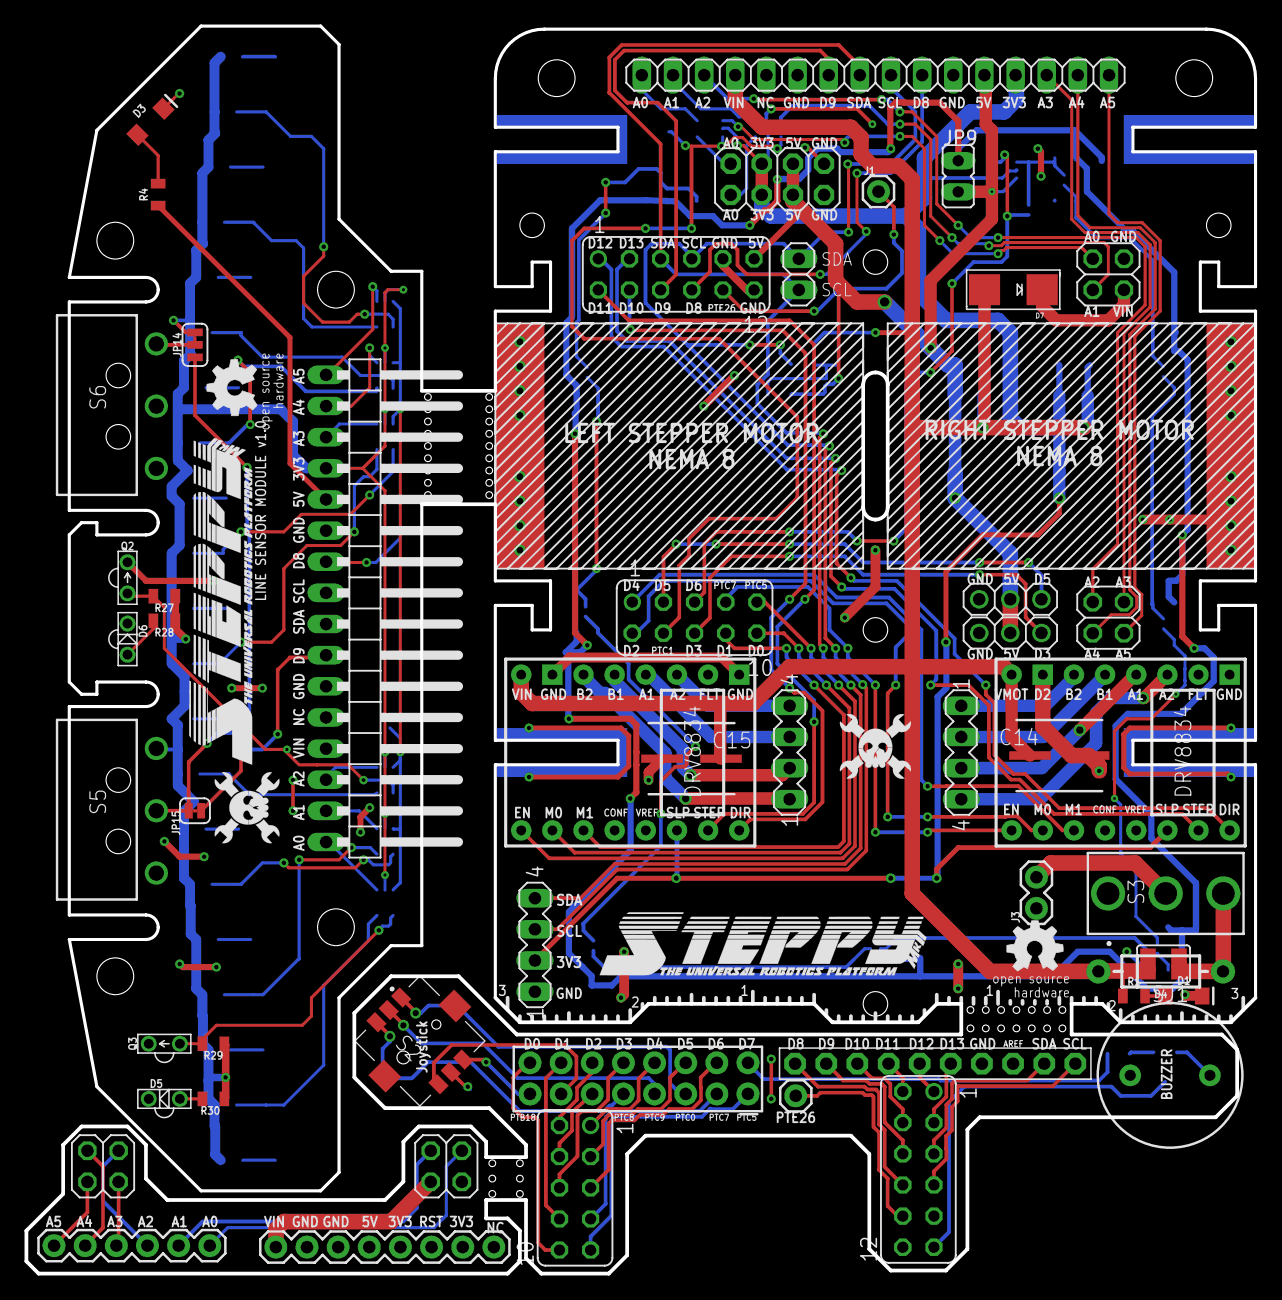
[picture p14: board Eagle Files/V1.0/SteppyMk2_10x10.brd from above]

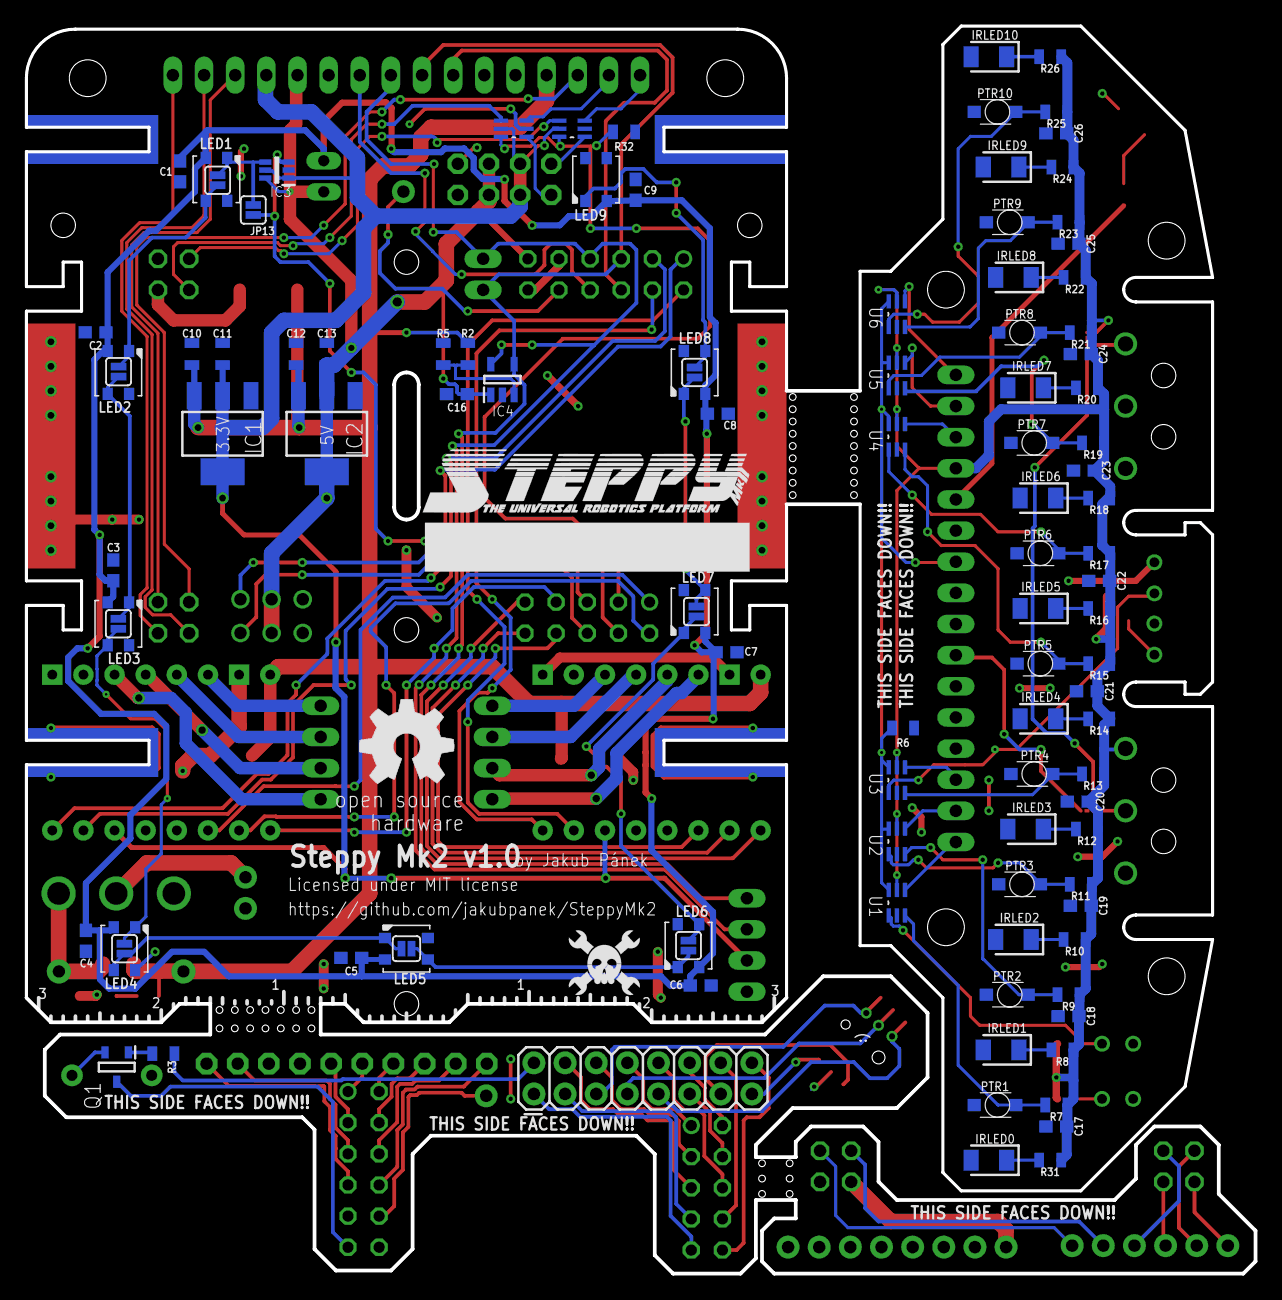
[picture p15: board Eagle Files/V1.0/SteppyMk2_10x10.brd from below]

Board: 2 copper layers, 100.2 x 101.8 mm, 156 parts (104 on the bottom side), 129 nets.

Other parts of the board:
GOLD_ORB_SM3: OSHWLOGOLOGO5MM; OSHW_5MM

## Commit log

2019-04-14 V1.0 Eagle files
    [SteppyMk2.brd, SteppyMk2.sch, SteppyMk2_10x10.brd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]
2019-04-14 Rename SteppyMk2.brd to Eagle Files/V1.0/SteppyMk2.brd
    [SteppyMk2.brd]
2019-04-14 Rename SteppyMk2.sch to Eagle Files/V1.0/SteppyMk2.sch
    [SteppyMk2.sch]
2019-04-14 Rename SteppyMk2_10x10.brd to Eagle Files/V1.0/SteppyMk2_10x10.brd
    [SteppyMk2_10x10.brd]
2019-04-14 Rename SteppyMk2_10x10.sch to Eagle Files/V1.0/SteppyMk2_10x10.sch
    [SteppyMk2_10x10.sch]
2019-04-14 Added model of SMD joystick cap
    [JoystickCap.stl]
2019-05-09 Added motor holder models
    [MotorHolderMiddle.stl, MotorHolderSide.stl]

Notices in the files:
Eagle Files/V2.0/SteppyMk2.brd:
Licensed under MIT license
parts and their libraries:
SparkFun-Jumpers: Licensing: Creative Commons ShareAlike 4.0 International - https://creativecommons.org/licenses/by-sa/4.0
